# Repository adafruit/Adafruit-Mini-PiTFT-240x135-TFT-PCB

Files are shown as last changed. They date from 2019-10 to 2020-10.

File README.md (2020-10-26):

## Adafruit Mini PiTFT - 135x240 and 240x240 Color TFT Add-ons for Raspberry Pi PCB

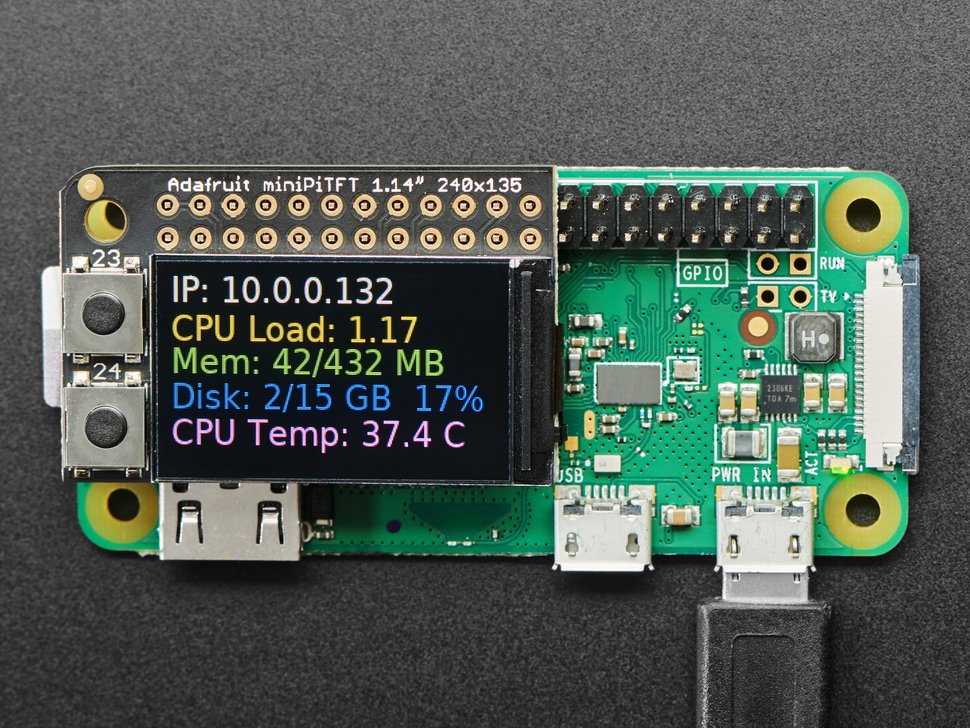
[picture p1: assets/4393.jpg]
<a href="http://www.adafruit.com/products/4393"><br/>
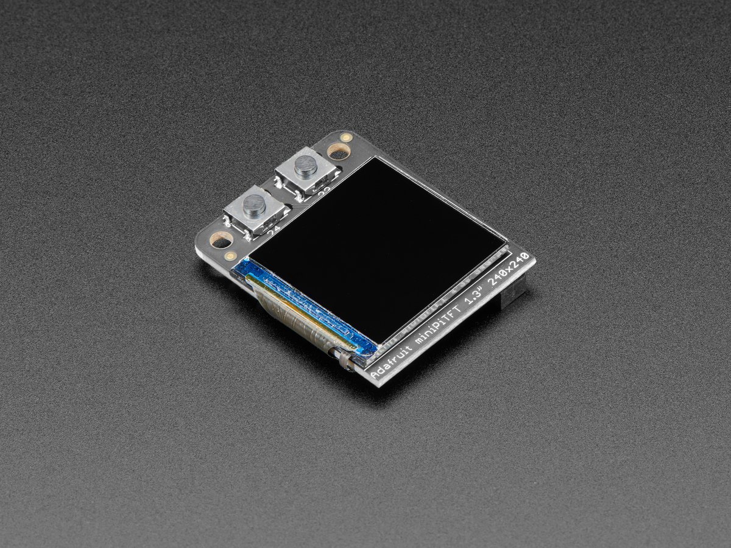
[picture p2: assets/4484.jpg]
<a href="http://www.adafruit.com/products/4484"><br/>
Click here to purchase one from the Adafruit shop</a>

PCB files for the Adafruit Mini PiTFT - 135x240 and 240x240 Color TFT Add-ons for Raspberry Pi. 

Format is EagleCAD schematic and board layout
* https://www.adafruit.com/product/4393
* https://www.adafruit.com/product/4484

### Description

If you're looking for the most compact li'l color display for a [Raspberry Pi](https://www.adafruit.com/category/361) (most likely a [Pi Zero](https://www.adafruit.com/category/813)) project, this might be just the thing you need!

The **Adafruit Mini PiTFT - 135x240 Color TFT Add-on for Raspberry Pi** and the **Adafruit Mini PiTFT - 1.3" 240x240 Color TFT Add-on for Raspberry Pi** are your little TFT pals, ready to snap onto any and all Raspberry Pi computers, to give you a little display. The Mini PiTFT comes with a full color 240x135 or 240x240 pixel IPS display with great visibility at all angles. The TFT uses only the SPI port so its very fast, and we leave plenty of pins remaining available for buttons, LEDs, sensors, etc. It's also nice and compact so it will fit into any case.

This display is super small, only about 1.14" diagonal or 1.3" diagonal, but since it is an IPS display, its very readable with high contrast and visibility. We had a little space on the top so we give you two tactile buttons on GPIO pins so you can create a simple user interface. [On the bottom we have a Qwiic/STEMMA QT connector for I2C sensors and device so you can plug and play any of our STEMMA QT devices](https://www.adafruit.com/?q=stemma%20qt).

Using the display is very easy, we have a kernel driver and Python library for the ST7789 chipset. You can set it up as a console output so you can have text and user interface through the Raspberry Pi OS or you draw images, text, whatever you like, using the Python imaging library. Our tests showed ~15 FPS update rates so you can do animations or simple video.

**Comes completely pre-assembled and tested** so you don't need to do anything but plug it in and install our Python code! **Works with any Raspberry Pi computer.**

### License

Adafruit invests time and resources providing this open source design, please support Adafruit and open-source hardware by purchasing products from [Adafruit](https://www.adafruit.com)!

Designed by Limor Fried/Ladyada for Adafruit Industries.

Creative Commons Attribution/Share-Alike, all text above must be included in any redistribution. 
See license.txt for additional details.

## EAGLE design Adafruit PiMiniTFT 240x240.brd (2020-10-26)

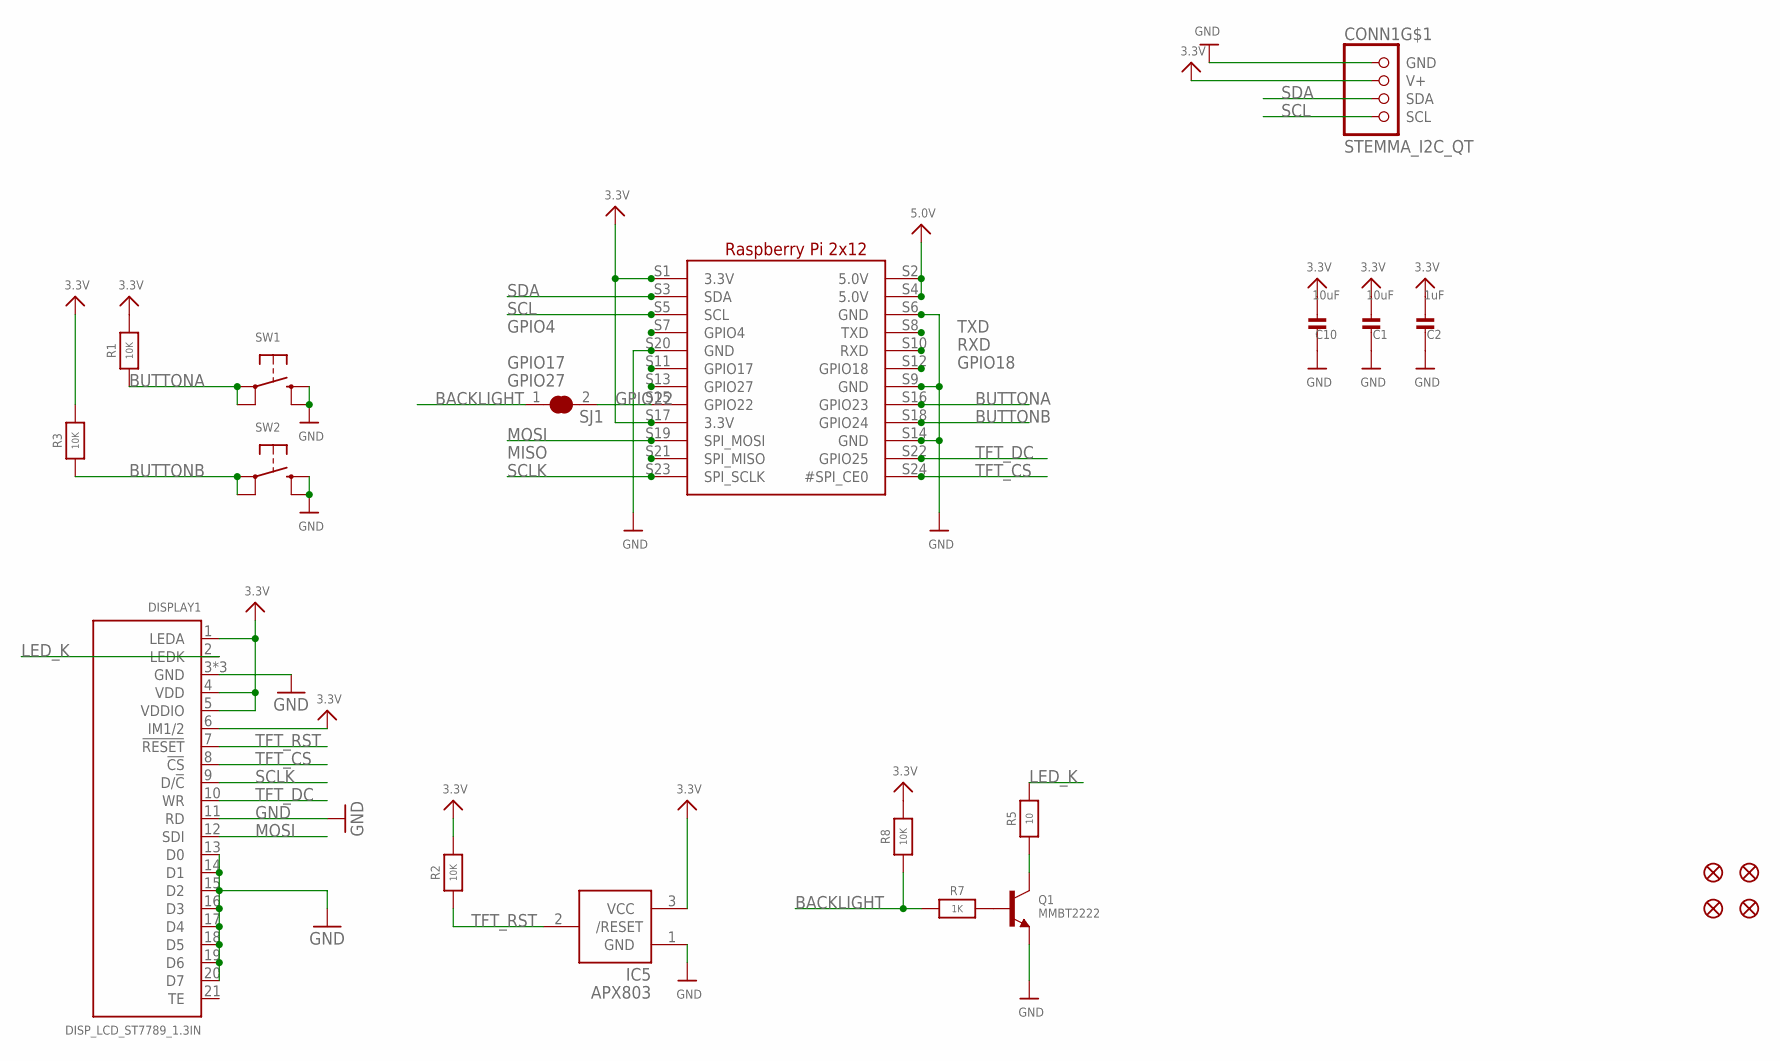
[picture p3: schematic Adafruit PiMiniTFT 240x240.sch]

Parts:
C1, C10: 10uF; 0805-NO
C2: 1uF; 0603-NO
CONN1: STEMMA_I2C_QT; JST_SH4
DISPLAY1: DISP_LCD_ST7789_1.3IN; TFT_1.3IN_240X240_24P
FID1, FID2, FID3, FID4: FIDUCIAL_1MM
IC5: APX803; SOT23
Q1: MMBT2222; SOT23-WIDE
R1, R2, R3, R8: 10K; 0603-NO
R5: 10; 0603-NO
R7: 1K; 0603-NO
RASPI1: RASPBERRYPI_2X12_SMT
SJ1: SOLDERJUMPER_CLOSED; SOLDERJUMPER_CLOSEDWIRE
SW1, SW2: SWITCH_TACT_SMT_EVQQ2_SMALL; EVQ-Q2_SMALLER

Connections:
3.3V: C1.2, C2.2, C10.2, CONN1.2 (V+), DISPLAY1.1 (LEDA), DISPLAY1.4 (VDD), DISPLAY1.5 (VDDIO), DISPLAY1.6 (IM1/2), IC5.3 (VCC), R1.2, R2.2, R3.2, R8.2, RASPI1.S1 (3.3V), RASPI1.S17 (3.3V)
5.0V: RASPI1.S2 (5.0V), RASPI1.S4 (5.0V)
BACKLIGHT: R7.1, R8.1, SJ1.1
BUTTONA: R1.1, RASPI1.S16 (GPIO23), SW1.A, SW1.A' (P1)
BUTTONB: R3.1, RASPI1.S18 (GPIO24), SW2.A, SW2.A' (P1)
GND: C1.1, C2.1, C10.1, CONN1.1 (GND), DISPLAY1.3 (GND), DISPLAY1.11 (RD), DISPLAY1.13 (D0), DISPLAY1.14 (D1), DISPLAY1.15 (D2), DISPLAY1.16 (D3), DISPLAY1.17 (D4), DISPLAY1.18 (D5), DISPLAY1.19 (D6), DISPLAY1.20 (D7), DISPLAY1.23 (GND), DISPLAY1.24 (GND), IC5.1 (GND), Q1.2 (E), RASPI1.S6 (GND), RASPI1.S9 (GND), RASPI1.S14 (GND), RASPI1.S20 (GND), SW1.B (S), SW1.B' (S1), SW2.B (S), SW2.B' (S1)
GPIO4: RASPI1.S7 (GPIO4)
GPIO17: RASPI1.S11 (GPIO17)
GPIO18: RASPI1.S12 (GPIO18)
GPIO22: RASPI1.S15 (GPIO22), SJ1.2
GPIO27: RASPI1.S13 (GPIO27)
LED_K: DISPLAY1.2 (LEDK), R5.2
MISO: RASPI1.S21 (SPI_MISO)
MOSI: DISPLAY1.12 (SDI), RASPI1.S19 (SPI_MOSI)
unnamed: Q1.1 (B), R7.2
unnamed: Q1.3 (C), R5.1
RXD: RASPI1.S10 (RXD)
SCL: CONN1.4 (SCL), RASPI1.S5 (SCL)
SCLK: DISPLAY1.9 (D/!C), RASPI1.S23 (SPI_SCLK)
SDA: CONN1.3 (SDA), RASPI1.S3 (SDA)
TFT_CS: DISPLAY1.8 (!CS), RASPI1.S24 (#SPI_CE0)
TFT_DC: DISPLAY1.10 (WR), RASPI1.S22 (GPIO25)
TFT_RST: DISPLAY1.7 (!RESET), IC5.2 (/RESET), R2.1
TXD: RASPI1.S8 (TXD)

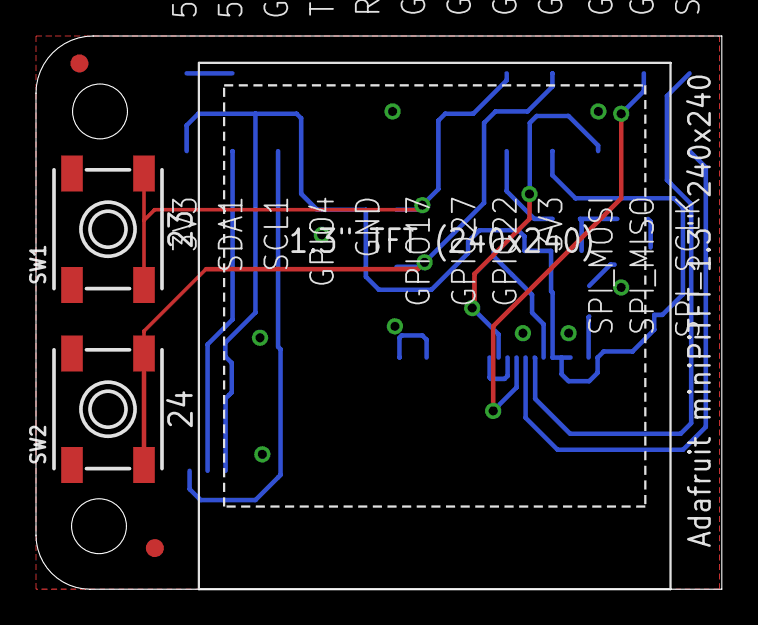
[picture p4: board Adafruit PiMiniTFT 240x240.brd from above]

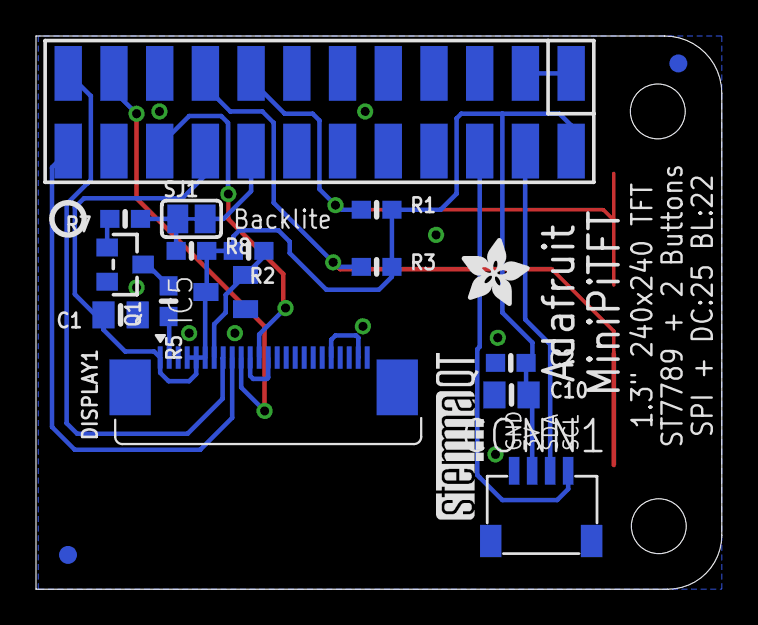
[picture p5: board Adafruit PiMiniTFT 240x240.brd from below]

Board: 2 copper layers, 38.1 x 30.7 mm, 24 parts (19 on the bottom side), 17 nets.

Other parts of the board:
U$4: MICROSD; ADAFRUIT_3.5MM
U$6: PCBFEAT-REV-040
U$15: STEMMAQT

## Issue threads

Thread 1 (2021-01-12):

Compatibility with displays without a chip select pin

james1236, 2021-01-12:
Could this be modified to allow compatibility with these kinds of 1.3" TFT displays that have no chip select pin?

https://uk.banggood.com/1_3-Inch-IPS-TFT-LCD-Display-240+240-Color-HD-LCD-Screen-3_3V-ST7789-Driver-Module-p-1383404.html

Thank you

ladyada, 2021-01-12:
if youre talking about firmware, no - the lack of CS causes the SPI mode to be different

Closed 2021-01-12.
